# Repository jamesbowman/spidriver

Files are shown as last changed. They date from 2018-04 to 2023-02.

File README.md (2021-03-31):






Full documentation is at
[spidriver.com](https://spidriver.com).

SPIDriver is a tool for controlling any SPI device from your PC's USB port.
It connects as a standard USB serial device, so there are no drivers to install.
The serial protocol is [very simple](/protocol.md),
and there are included drivers for

* Windows/Mac/Linux GUI
* Windows/Mac/Linux command-line
* Python 2 and 3
* Windows/Mac/Linux C/C++

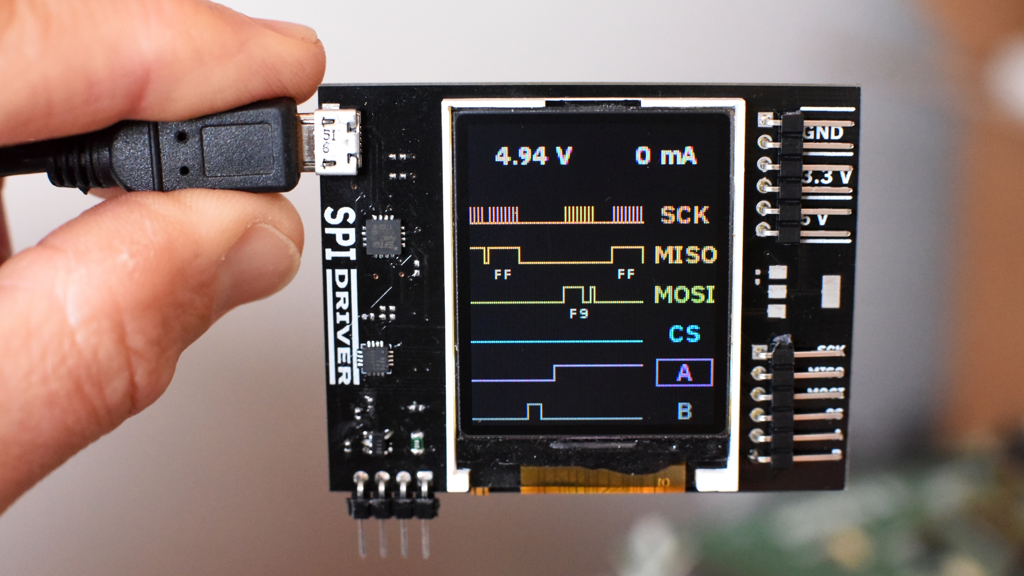
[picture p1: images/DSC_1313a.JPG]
front


## Contributed language bindings

The following bindings were contributed by SPIDriver community members:

* **.net** https://github.com/alandoherty/spidriver-net
* **rust** https://docs.rs/spidriver/0.1.0/spidriver/

[spidriver.com](https://spidriver.com)

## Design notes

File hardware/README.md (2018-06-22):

This is the PCB for the SPIDriver.
It uses a [SKiDL](https://github.com/xesscorp/skidl) to define the netlist.

PCB layout is done in KiCAD's pcbnew:

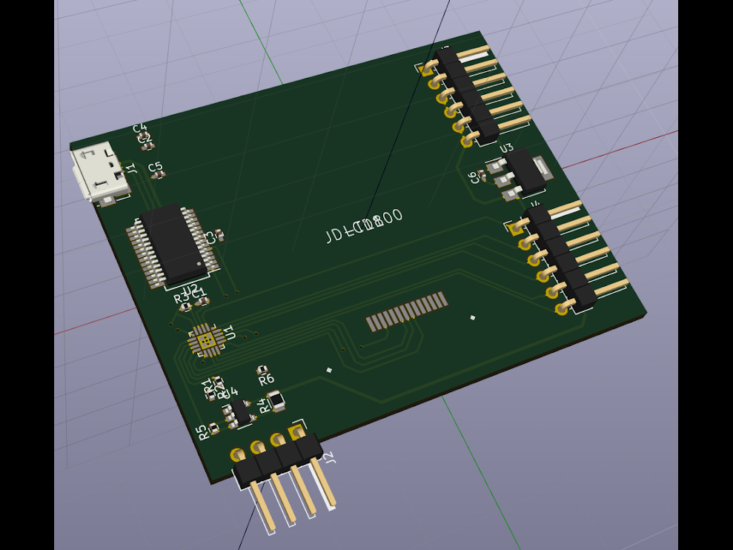
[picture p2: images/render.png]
pcbnew


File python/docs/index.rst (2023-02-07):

spidriver
=========

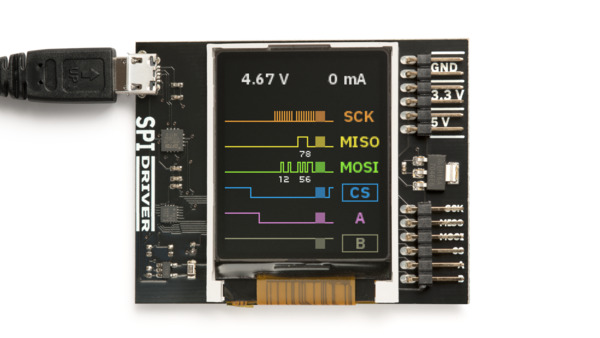
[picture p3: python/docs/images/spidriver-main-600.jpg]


`SPIDriver <https://spidriver.com>`_
is an easy-to-use, open source tool for controlling SPI devices over USB.
It works with Windows, Mac, and Linux, and has a built-in color screen
that shows a live "dashboard" of all the SPI activity.

.. toctree::
   :maxdepth: 2
   :caption: Contents:

The SPIDriver User Guide has complete information on the hardware:

https://spidriver.com/spidriver.pdf

System Requirements
===================

Because it is a pure Python module, ``spidriver`` can run on any system supported by ``pyserial``.
This includes:

- Windows 7 or 10
- Mac OS
- Linux, including all Ubuntu distributions

Both Python 2.7 and 3.x are supported.

Installation
============

The ``spidriver`` package can be installed from PyPI using ``pip``::

    $ pip install spidriver

Quick start
===========

To connect to an SPI flash and read its JEDEC id:

    >>> from spidriver import SPIDriver
    >>> s = SPIDriver("/dev/ttyUSB0") # change for your port
    >>> s.sel() # start command
    >>> s.write([0x9f]) # command 9F is READ JEDEC ID
    >>> list(s.read(3)) # read next 3 bytes
    [239, 64, 24]
    >>> s.unsel() # end command

The User Guide at https://spidriver.com/spidriver.pdf has more examples,
as does the
`SPIDriver repo on github <https://github.com/jamesbowman/spidriver/tree/master/python/samples>`_.

Module Contents
===============

.. autoclass:: spidriver.SPIDriver
   :member-order: bysource
   :members:
      sel,
      unsel,
      detach,
      read,
      write,
      writeread,
      seta,
      setb,
      setmode,
      getstatus

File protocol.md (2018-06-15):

Commands are:

    ?        transmit status info
    e <byte> echo <byte>
    s        select
    u        unselect
    a <byte> set A signal to 0/1
    b <byte> set B signal to 0/1
    x        disconnect from SPI bus
    80-bf    write and read 1-64 bytes
    c0-ff    write 1-64 bytes

So for example to select, then transfer two bytes 0x12, and unselect, the host sends 5 bytes:

    s
    0x81
    0x12
    0x34
    u

The command 0x81 is a two byte send/receive, so two bytes are returned to the PC.

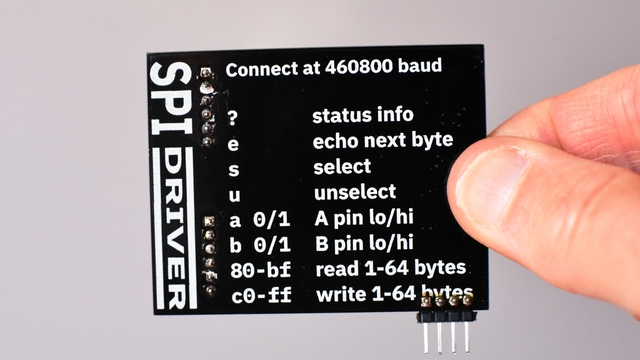
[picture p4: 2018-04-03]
images/small/DSC_1315a.JPG

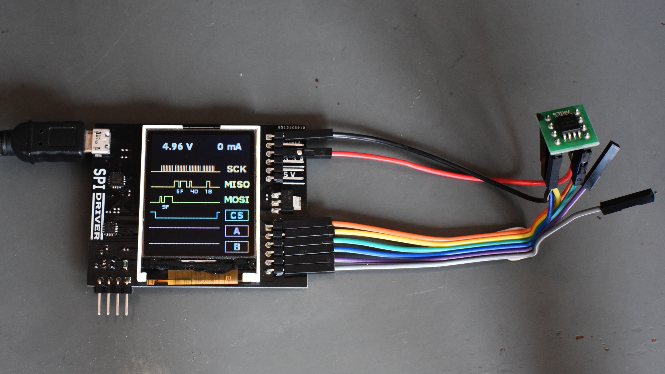
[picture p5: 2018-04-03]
images/DSC_1319a.JPG

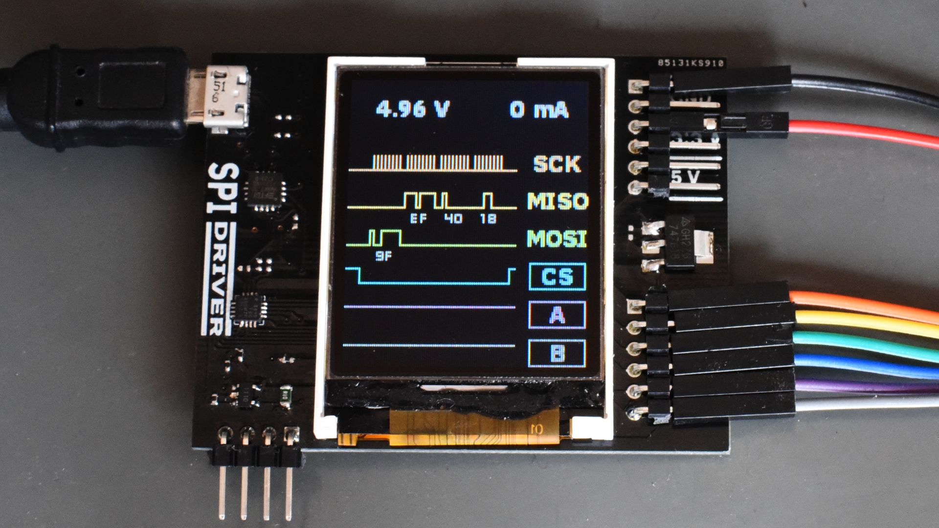
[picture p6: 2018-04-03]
images/DSC_1319b.JPG

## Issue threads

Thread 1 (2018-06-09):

Delightful project ... quick question(s)

RandoSY, 2018-06-09:
Hello!

Just wondering when you were going to follow up you introductory video (FEB SVFIG), and further clarify/share the amazing SiLab EFM8 My-forth tool-chain you built for this project?

Are your plans still on track to crowdfund your SPI monitor? Thanks for all your hard work on this!

Randy

jamesbowman, 2018-06-10:
Hi Randy,

Talking at June Svfig: definitely maybe. I'm not 100% sure I can attend Saturday.

The SPIDriver will launch in a few days. So many fingers are crossed. Please tell anyone who might be interested -- thanks!

RandoSY, 2018-06-15:
James,

150$ funded in TWO DAYS? Wow, you sir, are the man!

I will hope you share you tool set along the way J Gotta be some awesome real time performance in your rig…

Best,

Randy

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

jamesbowman, 2018-08-30:
Never did make it to the SVfig meeting... maybe Forth day 2018 in November!

Closed 2018-08-30.

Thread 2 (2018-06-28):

Passive monitoring?

osterwood, 2018-06-28:
In the future, could the SPI Driver be used to monitor traffic between an external SPI master and slave?

In this mode, I’d love to set a target byte sequence / trigger via the API and a number of bytes to read out once that trigger is seen.  Or the hardware could just provide a continuous stream of data to the computer and triggering / masking could happen there.

jamesbowman, 2019-04-14:
On "must have" list for next version. Closing.

Closed 2019-04-14.

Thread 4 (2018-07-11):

Document MOSI/MISO line sharing

jamesbowman, 2018-07-11:
Using a diode like the circuit used here:
https://github.com/dcwbrown/dwire-debug

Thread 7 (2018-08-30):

win32 spigui should cope properly with multiple serial devices

jamesbowman, 2018-08-30:
When there is one serial device, it should just connect to it.

But when there are multiple serial devices, it should not connect, and wait for the user to pick one from the pulldown.

jamesbowman, 2018-08-30:
Fixed, closing.

Closed 2018-08-30.

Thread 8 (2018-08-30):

Command-line should have a 't' command for bidirectional transfer

jamesbowman, 2018-08-30:
't' should act like 'w', but print out the received bytes.

Suggested in this thread:
http://gameduino2.proboards.com/thread/852/spidriver-running-gameduino3?page=1&scrollTo=2221

maxnil, 2019-06-15:
Any progress on this?

0xStuart, 2021-07-11:
Is that why I cant seem to get anything out of the Atmel M90E26?  You have to write 8 bits, and it immediately returns 16 bits.  Except I see nothing.

This is from the manual.

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

On the spidriver, I see the clock being interrupted, between flipping between write and read.

jamesbowman, 2021-07-11:
This diagram looks half-duplex, so the right sequence should be:

    spicl <device> s w 0x40 r 2 u

0xStuart, 2021-07-11:
It operates like it's half-duplex, but the manual says full-duplex.
The SCK doesn't look the same as the diagram, don't know if that's relevant.

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

jamesbowman, 2021-07-11:
This looks fine - the gaps on SCK are just the inter-byte pauses.

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

Hmm, one idea... datasheet does say that it expects a '1' bit before the 7-bit register address. So changing 0x49 there to 0xc9 might work?

0xStuart, 2021-07-12:
Good call. That wasn't quite it, but I got it working.  I discovered I have a different chip variation to the manual.  Thanks.

benner, 2023-09-13:
I have same issue - I need to receive same time I'm transmitting (full duplex).

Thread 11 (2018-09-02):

Under WSL, no serial device appears

jamesbowman, 2018-09-02:
Reported by @gojimmypi:

> Device is not currently supported in [WSL](https://docs.microsoft.com/en-us/windows/wsl/about), as no device appears in /dev/

jamesbowman, 2018-09-02:
This blog entry explains their naming conventions:

https://blogs.msdn.microsoft.com/wsl/2017/04/14/serial-support-on-the-windows-subsystem-for-linux/

So I would expect ``COM16`` to appear under WSL as ``/dev/ttyS16`` - does this make sense?

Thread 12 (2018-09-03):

Make a proper package for Mac

jamesbowman, 2018-09-03:
Is currently a raw executable. Should be a proper package.

jamesbowman, 2018-09-03:
Walkthough:

http://juusosalonen.com/post/139067064745/demystifying-pkgbuild-in-os-x

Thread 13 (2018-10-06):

All indicators colored bars full all the times.

kirill-chilingarashvili, 2018-10-06:
I just had a chance to test a device,
The voltage above and current indicators work as expected,
bu all of
- SCK
- MISO
- MOSI
- CS
- A
- B

bars are filled with color all the time.
I tried to follow the tutorials - the border around CS, A symbols blink, but the bars designated to show signal are filled all the time.
I tried the image rendering (TFT demo) sample, and the TFT is white and bars are filler.

I am sorry for noob question -  really just got my SPIDriver and tried to follow the tutorials

Can you please help me - where to start debugging this

jamesbowman, 2018-10-06:
Definitely sounds like a hardware issue. Email me at jamesb@excamera.com to arrange a replacement.

Closed 2019-04-14.

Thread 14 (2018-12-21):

Absolutelly unclear instructions

Kabron287, 2018-12-21:
Windows 10 x64
executing **pip install pillow spidriver**
I got a huge output with meaningnone sense. See attach.
[pip_output.txt](https://github.com/jamesbowman/spidriver/files/2702348/pip_output.txt)

executing **python spigui.py**
I got
`d:\Down\SPI_Driver\spidriver-master\python\samples>python spigui.py
Traceback (most recent call last):
  File "spigui.py", line 9, in <module>
    import wx
ImportError: No module named 'wx'`
and so on, nothing works.
 maybe instructions have to be more comprehensive?

MartyMacGyver, 2019-01-30:
Short story: Install Python 3.6 or 3.7 (I'm using 3.7) and use that. I suspect your old Python 3.4 is the first problem here.

Longer story: Even then the gui won't work, because it's only made to enumerate ports on OSX and Linux. However, once you know what port you're on (e.g., "`COM3:`"), you can make a simple hack of spigui.py to make it work:

After the line `self.devs = self.devices()`
Add the line `self.devs = {'COM3:': 'COM3:'}` (with your COM port in it)

Then it (hopefully) will work better. Mine works with this.

I'd also suggest you update the title here to be more informative - something like "Unable to run samples using Windows 10" since that's really the main problem here.

jamesbowman, 2019-01-30:
@Kabron287 was getting an error because of missing 'wx' - is it included in Python 3.7 on Windows?

Or did you install wx by doing something like:
https://wxpython.org/pages/downloads/index.html

I have opened #17 for the port enumeration problem. Thanks

MartyMacGyver, 2019-01-30:
The warnings about python_requires and the `The headers or library files could not be found for zlib, a required dependency when compiling Pillow from source.` error are what I see in their logfile here. The former suggests outdated Python, but the latter is because Pillow is being compiled (a binary wheel would be the way to go for that.) Maybe updating pip would allow that, but installing a current Python might be a better way to go to get a functional install - 3.4 is also just about EOL:

https://www.python.org/dev/peps/pep-0429/

jamesbowman, 2019-04-14:
Python GUI should:
- [ ] catch missing wx and show a helpful message
- [ ] enumerate ports properly on Windows

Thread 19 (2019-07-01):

Python code does not properly calculate size / does not properly handle some devices

dshadoff, 2019-07-01:
While trying to identify/read a 8KB FeRAM device MB85RS64V, the JEDEC ID is properly identified (0x04 0x7F 0x03), but the python code then goes into an infinite loop grabbing JEDEC ID again and again instead of determining memory size (which is 64 kbit / 8KB).

Product was purchased here: https://www.adafruit.com/product/1897
Datasheet here: http://www.adafruit.com/datasheets/MB85RS64V-DS501-00015-4v0-E.pdf

Likewise, a 128KB FeRAM MR45V100A was properly identified as (0xae 0x83 0x09), but was improperly identified as 512 bytes (actual size = 1Mbit / 128KB).

jamesbowman, 2019-07-01:
Fixed the infinite loop bug, and pushed to PyPI:
https://pypi.org/project/spidriver/

You can specify the size on the command-line using the ``-s`` argument, so for the MB85RS64V use ``-s 65536``, and for MR45V100A ``-s 131072``. This is meant for parts where the size isn't computable from the third ID byte, like these.

However reading further down the MB85RS64V datasheet, I see that it uses 16-bit addresses, and the flash tool assumes 24-bit addresses.
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

However the MR45V100A does use 24-bit addressing, so it might work - please let me know.
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

dshadoff, 2019-07-02:
Thanks, the infinite loop bug appears to be fixed.

The third-byte size computation... may not be as straightforward as you had thought.
I tested a AT25SF041 (very common 4Mb / 512KB Flash), which has JEDEC ID (0x1f 0x84 0x01)... this clearly also doesn't follow your expected rules.

As a result, it would be helpful if the spidriver.pdf file could be updated with this point about memory size, including the '-s <size>' operand for the python script.

bitshiftnetau, 2020-08-10:
Not fixed. Trying to read a [winbond 25Q64/32f](https://www.winbond.com/resource-files/w25q64fv%20revq%2006142016.pdf) and the output "Got JEDEC ID: xx xx xx" outputs on infinite loop. It does get the JEDEC ID.

I have tried connecting the WP and HOLD pins (3 & 5 respectively) to A and B and all 3 combinations of each i.e. WP & HOLD, just WP, just HOLD and nothing seems to work.

I am running:

`python flash.py -h /dev/ttyUSB0`

And have confirmed it does not work when the device and indeed the clip itself are not connected.

I have an updated version of spidriver installed and I am using the following flash.py example code:

```

#!/usr/bin/env python3

from spidriver import SPIDriver
import struct
import time
import sys
import getopt

def hexdump(s):
    def toprint(c):
        if 32 <= c < 127:
            return chr(c)
        else:
            return "."
    def hexline(s):
        bb = struct.unpack("16B", s)
        return (" ".join(["%02x" % c for c in bb]).ljust(49) +
                "|" + "".join([toprint(c) for c in bb]).ljust(16) + "|")
    return "\n".join([hexline(s[i:i+16]) for i in range(0, len(s), 16)])

if __name__ == '__main__':
    try:
        optlist, args = getopt.getopt(sys.argv[1:], "h:r:w:s:")
    except getopt.GetoptError as reason:
        print()
        print('usage: flash [ -h device ] [ -r file ] [ -w file ] [-s size]')
        print()
        print()
        sys.exit(1)
    optdict = dict(optlist)

    s = SPIDriver(optdict.get('-h', "/dev/ttyUSB0"))
    s.seta(0)
    s.unsel()

    size = int(optdict.get('-s', "0"))

                                # Some primitives for generic flash
    def command(b):
        s.unsel()
        s.sel()
        s.writeread(b)

    def idcode():
        command([0x9f])
        return s.read(3)

    def write_enable():
        command([0x06])

    def status():
        command([0x05])
        (r,) = struct.unpack("B", s.read(1))
        return r

    def wait_ready():
        while True:
            r = status()
            if (r & 1) == 0:
                break

    def addr24(a):
        return [(a >> 16) & 0xff, (a >> 8) & 0xff, a & 0xff]

    def page_program(a, b256):
        # print('page_program', a)
        write_enable()
        command([0x02] + addr24(a))
        s.writeread(b256)
        wait_ready()

    def erase_sector(a):
        # print('erase sector', a)
        write_enable()
        command([0xd8] + addr24(a))
        wait_ready()

    def read(a):
        command([0x03] + addr24(a))

    while True:
        ids = struct.unpack("BBB", idcode())
        print("Got JEDEC ID: %02x %02x %02x" % ids)
        if size > 0:
            break
        if ids[0] not in (0x00, 0xff) and (1 <= ids[2] < 22):
            break
    if size == 0:
        size = 1 << ids[2]
    print("Flash size is %d bytes" % size)

    print("Status is %02x" % status())

    if '-r' in optdict:
        read(0)
        chunk = 8 * 1024
        size,chunk = 128,128
        with open(optdict['-r'], "wb") as f:
            for a in range(0, size, chunk):
                d = s.read(chunk)
                print(d)
                f.write(d)
                print("%d/%d KBytes" % (a / 1024, size / 1024))
    if '-w' in optdict:
        write_enable()
        command([0xc7])
        wait_ready()
        with open(optdict['-w'], "rb") as f:
            for a in range(0, size, 256):
                d = f.read(256)
                if len(d) == 0:
                    break
                page_program(a, d)
                print("%d/%d KBytes" % (a / 1024, size / 1024))
    write_enable()

    s.unsel()
    s.seta(1)
    s.detach()

```

biboc, 2022-11-04:
Agree with @dshadoff , size calculation does not work as expected for my m25p20 memory
https://media-www.micron.com/-/media/client/global/documents/products/data-sheet/nor-flash/serial-nor/m25p/m25p20.pdf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

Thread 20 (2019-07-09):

spidriver.pdf instructions for SPI Flash should connect /HOLD

dshadoff, 2019-07-09:
While using SPIFlash to read/write FeRAM device MR45V100A, I found that JEDEC ID was identified as {0x00, 0x00, 0x00} 90-99% of the time when the /HOLD line (pin 7 on SOP package) was left unconnected (as is demonstrated in the spidriver.pdf instruction file).

The datasheet for the device implied that both loose wires (/WP and /HOLD) should be brought to a logic "high", but I found that the JEDEC ID required just bringing /HOLD high.

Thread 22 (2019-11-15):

How can I debug, readout MOSI, MISO, CLK & CS from working Device under Test (DUT)

Hbra9774, 2019-11-15:
Is it possible with SPIdriver to monitor, Log a SPI-bus in a DUT ?

jamesbowman, 2019-11-15:
SPIDriver is output-only, it cannot monitor or log from an existing SPI bus.

Closed 2019-11-15.

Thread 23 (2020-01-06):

Would love build instructions for the GUIs

bitshiftnetau, 2020-01-06:
Doesn't seem to be a Makefile or any build instructions for the GUIs, I know you host the executables and that's great but seeing as you've opened the source it would be great to build from there.

Thoughts?

jamesbowman, 2020-01-06:
The Windows GUI is cross-compiled on Linux, the Makefile is in C/win32gui:

https://github.com/jamesbowman/spidriver/tree/master/c/win32gui

The Linux.Mac GUI is the Python gui.py
https://github.com/jamesbowman/spidriver/blob/master/python/samples/gui.py

It is made into an executable with `pyinstaller` - the I2CDriver Readme gives the command-line:

https://github.com/jamesbowman/i2cdriver

bitshiftnetau, 2020-01-06:
Awesome man, I've built a package for Arch Linux that builds spicl and also a shared library, then installs to the system. I'll do the same for the GUIs based on your instructions above.

Also, just a side note: this device is the best thing I have ever purchased. Thank you!

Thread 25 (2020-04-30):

Mode control - how?

mgaman, 2020-04-30:
How can I set modes 0-3? From what I see on the screen SCLK polarity is always Idle at 0.
There are no instructions as how to change it

jamesbowman, 2020-04-30:
Yes, that is correct. SPIDriver only runs in mode 0.

What device do you have that runs in another mode?

mgaman, 2020-05-01:
I don't, yet but do anticipate in the near future.
Can it be changed via the serial connection or is it hard wired in the device firmware?

nicktramp, 2020-07-22:
I was looking to use SPIDriver with the [Melexis MLX90393](https://www.melexis.com/en/product/MLX90393/Triaxis-Micropower-Magnetometer), which uses SPI mode 3. Are other modes planned? I would offer to help implement, but I've never encountered Forth outside this project, so I'm afraid I wouldn't be much help...

movingfox, 2022-02-13:
I can see that it's hard to be done because the firmware needs to drive st7735s at SPI mode 0 as well. Could you release a 'blind' version of firmware for those who'd like to have spidriver2 mode selection ? That seems to be a dirty but quick fix.

By the way, the file `cal-b3.fs` is missing in the firmware folder. Could you upload it?

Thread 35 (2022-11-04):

flash.py: size is erased with read option

biboc, 2022-11-04:
I read my SPI memory with

The flash.py program reads only two bytes, why?
In the code, I don't get why you replace size variable at line https://github.com/jamesbowman/spidriver/blob/master/python/samples/flash.py#L97

```
    if '-r' in optdict:
        read(0)
        chunk = 8 * 1024
        size,chunk = 128,128
        with open(optdict['-r'], "wb") as f:
```

By commenting the line `size,chunk = 128,128`, it works

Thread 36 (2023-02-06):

Pause between SPI transactions

Rodgers-PAC-Lab, 2023-02-06:
I'm trying to read data from a sensor with a pretty fast sample rate, so I'm looking to get pretty close to the 500 kbps rate on the SPIDriver. I'm using one of the cheap Salae-8 knockoff logic analyzers and Pulseview for troubleshooting. I noticed that, while the actual SPI transactions are measuring 490 kHz, there's always a 30 microsecond pause between bytes.

What's the reason for these pauses, and is there any way to remove the delays? Here's a screenshot of what I see in Pulseview (sampling at 24 MHz) when I use the read(10) command to read 10 bytes.

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

jamesbowman, 2023-02-06:
That is puzzling. I expect there to be very little time between bytes.
For ``read(10)`` there's  be a delay every **10** bytes, because of the API overhead, but not every byte.

Couple of questions:

Is that ``read(10)`` in Python?

Please can you post a zoomed-out screenshot to confirm the inter-byte delay?

Rodgers-PAC-Lab, 2023-02-06:
Yeah, it's in Python. Just s = SPIDriver("/dev/SPIDriver"), then some setup code where I use a and b outputs to toggle a reset pin and start pin to wake up the peripheral, then s.read(10) and that's what I get.

The device is an ADS1299 EEG chip, but I'm pretty sure it's not an issue with the device. When I snoop on its SPI transactions with TI's demo software it doesn't have any gaps in SCLK. I could try SPIDriver with a different peripheral if you think that's worth checking though.

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

jamesbowman, 2023-02-06:
I'm just running the SPIDriver on the bench here and I see the same thing. The issue is that SPIDriver uses two-way communication to implement reads. (SPI **Writes** are fast, which is my confusion.) This introduces a read-write latency over the USB.

So yes, unfortunately this is a feature of the SPIDriver, at least the current version.

Have you set the USB latency timer to zero? That might help in this case:

    setserial /dev/<tty_name> low_latency

Rodgers-PAC-Lab, 2023-02-06:
Alas, that didn't change much. Brought it down to 29 us.

That makes sense though, thanks for explaining it. Even if SPIDriver isn't fast enough for our final application it's been a great troubleshooting tool.

Rodgers-PAC-Lab, 2023-02-09:
Quick question: would this also happen if we used the C/C++ driver? I see that the EFM8BB1 MCU datasheet claims speeds up to 24 MHz. I'm way less competent in C though, so I'd hate to spend the time figuring it out only to learn it's still too slow.

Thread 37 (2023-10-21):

Use with modm platform

botoxparty, 2023-10-21:
Hi,

I would love to be able to use this device with [modm](https://github.com/modm-io/modm).

I unfortunately don't have the in-depth knowledge of developing linux drivers to be able to refactor the existing linux driver to be compatible with the project. See https://github.com/modm-io/modm/issues/1094

If anyone would support me with developing this I would love to work together.

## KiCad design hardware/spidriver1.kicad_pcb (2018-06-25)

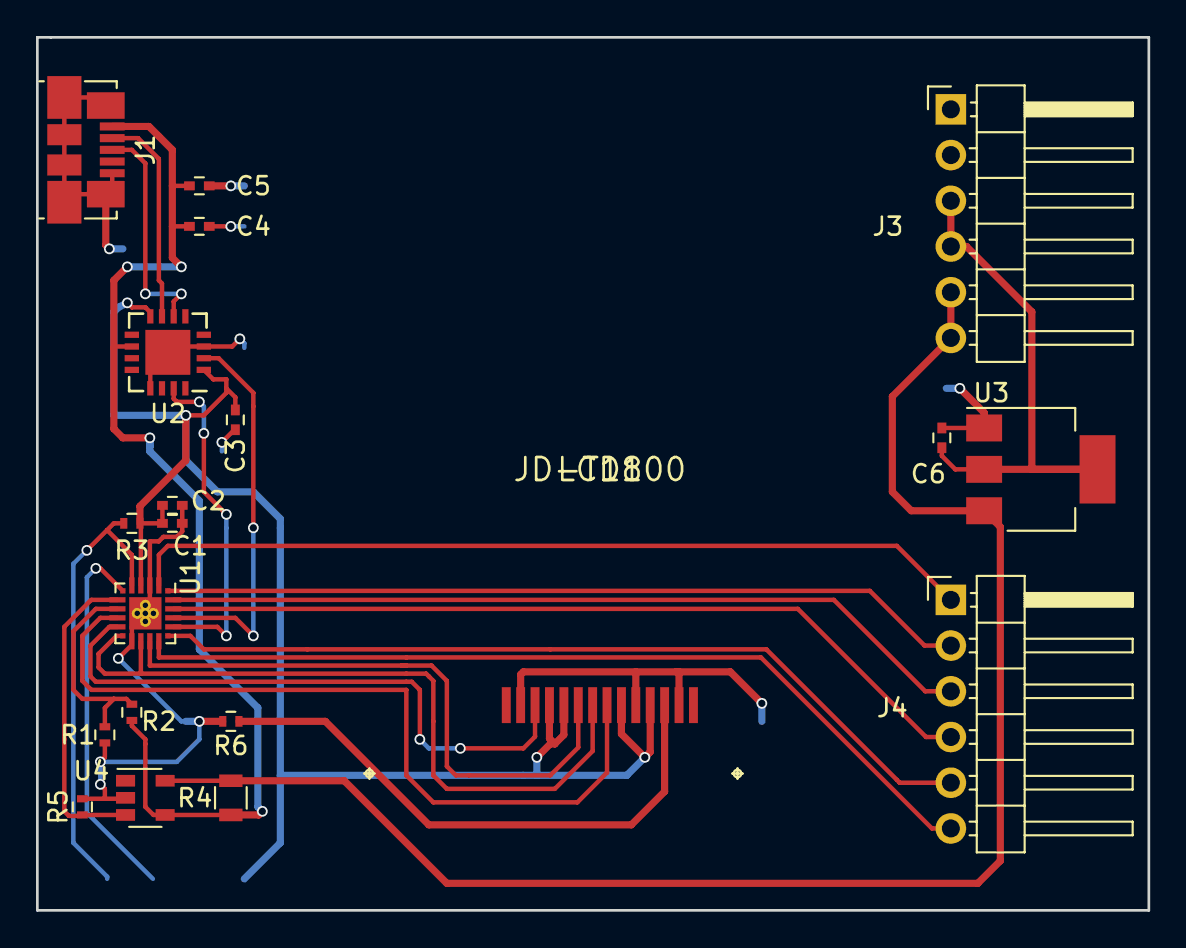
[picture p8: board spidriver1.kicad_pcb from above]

Board: 2 copper layers, 61.8 x 48.5 mm, 21 parts (1 on the bottom side), 24 nets.

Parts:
C1, C3, C4, C6: 0.1uF; C_0402
C2: 1uF; C_0402
C5: 10uF; C_0402
J1: USB_OTG; USB_Micro-B_Molex_47346-0001
J2: Conn_01x04_Male; POGO4
J3, J4: Conn_01x06_Male; Pin_Header_Angled_1x06_Pitch2.54mm
LCD1: JD-T1800
R1: 1180; R_0402
R2: 1000; R_0402
R3: 1K; R_0402
R4: .1; R_0805
R5: 12K; R_0402
R6: 22; R_0402
U1: EFM8BB10F8G-A-QFN20; SiliconLabs_QFN-20-1EP_3x3mm_Pitch0.5mm_ThermalVias
U2: FT230XQ; QFN-16-1EP_4x4mm_Pitch0.65mm
U3: AP1117-15; SOT-223-3Lead_TabPin2
U4: ZXCT1110; SOT-23-5

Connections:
3.3V: C1.1, C2.1, C3.1, J2.1, LCD1.4, LCD1.6, LCD1.10, LCD1.11, R3.2, U1.4, U2.1, U2.8
3.3VB: C6.1, J3.3, J3.4, U3.2
5V: C4.1, C5.1, J1.1, R1.1, R4.1, U2.10, U4.4
5VB: J3.5, J3.6, R4.2, U3.3, U4.5
GND: C1.2, C2.2, C3.2, C4.2, C5.2, C6.2, J1.5, J1.6, J2.2, J3.1, J3.2, LCD1.2, LCD1.5, LCD1.13, R2.2, R5.2, R6.2, U1.3, U1.12, U1.21, U2.3, U2.13, U2.17, U3.1, U4.2
unnamed: R1.2, R2.1, U1.8
unnamed: J2.4, R3.1, U1.5
unnamed: U1.18, U2.2
unnamed: U1.17, U2.15
unnamed: R5.1, U1.7, U4.3
unnamed: J2.3, U1.6
unnamed: J4.1, U1.2
unnamed: J4.2, U1.1
unnamed: J4.3, U1.20
unnamed: J4.4, U1.19
unnamed: J4.5, U1.16
unnamed: J4.6, U1.15
unnamed: LCD1.9, U1.14
unnamed: LCD1.8, U1.11, U1.13
unnamed: LCD1.12, U1.10
unnamed: LCD1.7, U1.9
unnamed: LCD1.3, R6.1
unnamed: J1.3, U2.6
unnamed: J1.2, U2.7

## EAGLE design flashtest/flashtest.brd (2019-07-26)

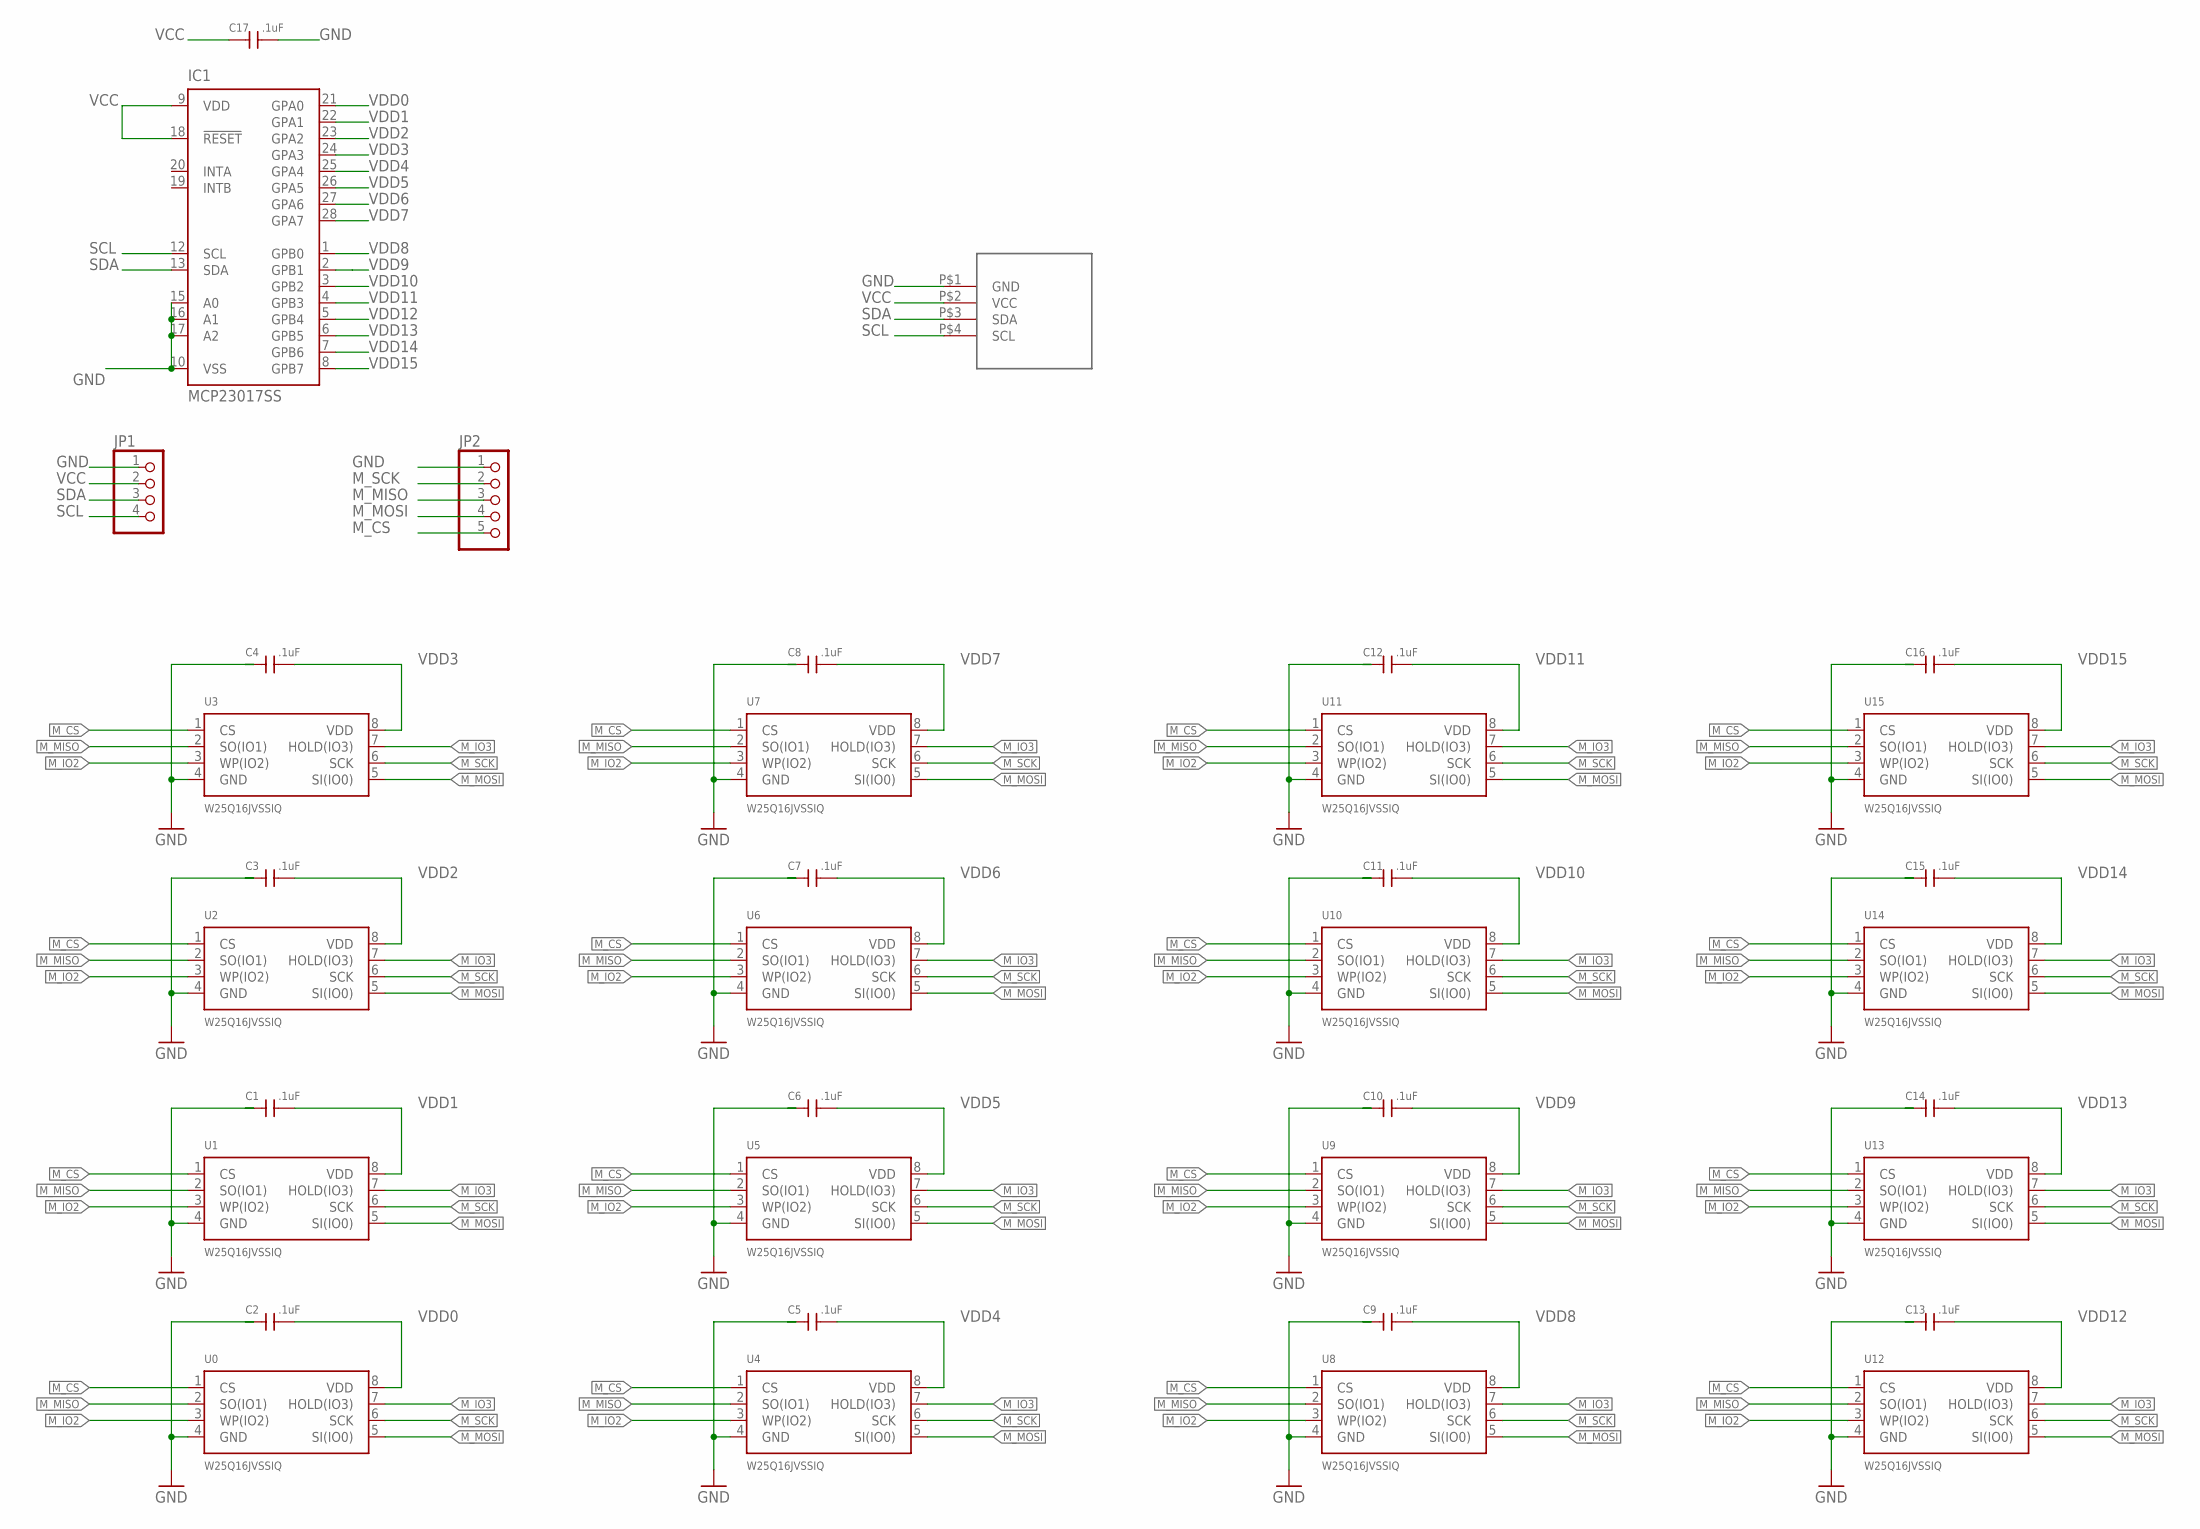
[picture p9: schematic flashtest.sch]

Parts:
C1, C2, C3, C4, C5, C6, C7, C8, C9, C10, C11, C12, C13, C14, C15, C16, C17: .1uF; 0603@1
IC1: MCP23017SS; SSOP28
JP1: PINHD-1X4; 1X04
JP2: PINHD-1X5; 1X05
U0, U1, U2, U3, U4, U5, U6, U7, U8, U9, U10, U11, U12, U13, U14, U15: W25Q16JVSSIQ; SOIC-8
U$1: I2C

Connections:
GND: C1.1, C2.1, C3.1, C4.1, C5.1, C6.1, C7.1, C8.1, C9.1, C10.1, C11.1, C12.1, C13.1, C14.1, C15.1, C16.1, C17.2, IC1.10 (VSS), IC1.15 (A0), IC1.16 (A1), IC1.17 (A2), JP1.1, JP2.1, U0.4 (GND), U1.4 (GND), U2.4 (GND), U3.4 (GND), U4.4 (GND), U5.4 (GND), U6.4 (GND), U7.4 (GND), U8.4 (GND), U9.4 (GND), U10.4 (GND), U11.4 (GND), U12.4 (GND), U13.4 (GND), U14.4 (GND), U15.4 (GND), U$1.P$1 (GND)
M_CS: JP2.5, U0.1 (CS), U1.1 (CS), U2.1 (CS), U3.1 (CS), U4.1 (CS), U5.1 (CS), U6.1 (CS), U7.1 (CS), U8.1 (CS), U9.1 (CS), U10.1 (CS), U11.1 (CS), U12.1 (CS), U13.1 (CS), U14.1 (CS), U15.1 (CS)
M_IO2: U0.3 (WP(IO2)), U1.3 (WP(IO2)), U2.3 (WP(IO2)), U3.3 (WP(IO2)), U4.3 (WP(IO2)), U5.3 (WP(IO2)), U6.3 (WP(IO2)), U7.3 (WP(IO2)), U8.3 (WP(IO2)), U9.3 (WP(IO2)), U10.3 (WP(IO2)), U11.3 (WP(IO2)), U12.3 (WP(IO2)), U13.3 (WP(IO2)), U14.3 (WP(IO2)), U15.3 (WP(IO2))
M_IO3: U0.7 (HOLD(IO3)), U1.7 (HOLD(IO3)), U2.7 (HOLD(IO3)), U3.7 (HOLD(IO3)), U4.7 (HOLD(IO3)), U5.7 (HOLD(IO3)), U6.7 (HOLD(IO3)), U7.7 (HOLD(IO3)), U8.7 (HOLD(IO3)), U9.7 (HOLD(IO3)), U10.7 (HOLD(IO3)), U11.7 (HOLD(IO3)), U12.7 (HOLD(IO3)), U13.7 (HOLD(IO3)), U14.7 (HOLD(IO3)), U15.7 (HOLD(IO3))
M_MISO: JP2.3, U0.2 (SO(IO1)), U1.2 (SO(IO1)), U2.2 (SO(IO1)), U3.2 (SO(IO1)), U4.2 (SO(IO1)), U5.2 (SO(IO1)), U6.2 (SO(IO1)), U7.2 (SO(IO1)), U8.2 (SO(IO1)), U9.2 (SO(IO1)), U10.2 (SO(IO1)), U11.2 (SO(IO1)), U12.2 (SO(IO1)), U13.2 (SO(IO1)), U14.2 (SO(IO1)), U15.2 (SO(IO1))
M_MOSI: JP2.4, U0.5 (SI(IO0)), U1.5 (SI(IO0)), U2.5 (SI(IO0)), U3.5 (SI(IO0)), U4.5 (SI(IO0)), U5.5 (SI(IO0)), U6.5 (SI(IO0)), U7.5 (SI(IO0)), U8.5 (SI(IO0)), U9.5 (SI(IO0)), U10.5 (SI(IO0)), U11.5 (SI(IO0)), U12.5 (SI(IO0)), U13.5 (SI(IO0)), U14.5 (SI(IO0)), U15.5 (SI(IO0))
M_SCK: JP2.2, U0.6 (SCK), U1.6 (SCK), U2.6 (SCK), U3.6 (SCK), U4.6 (SCK), U5.6 (SCK), U6.6 (SCK), U7.6 (SCK), U8.6 (SCK), U9.6 (SCK), U10.6 (SCK), U11.6 (SCK), U12.6 (SCK), U13.6 (SCK), U14.6 (SCK), U15.6 (SCK)
SCL: IC1.12 (SCL), JP1.4, U$1.P$4 (SCL)
SDA: IC1.13 (SDA), JP1.3, U$1.P$3 (SDA)
VCC: C17.1, IC1.9 (VDD), IC1.18 (!RESET), JP1.2, U$1.P$2 (VCC)
VDD0: C2.2, IC1.21 (GPA0), U0.8 (VDD)
VDD1: C1.2, IC1.22 (GPA1), U1.8 (VDD)
VDD2: C3.2, IC1.23 (GPA2), U2.8 (VDD)
VDD3: C4.2, IC1.24 (GPA3), U3.8 (VDD)
VDD4: C5.2, IC1.25 (GPA4), U4.8 (VDD)
VDD5: C6.2, IC1.26 (GPA5), U5.8 (VDD)
VDD6: C7.2, IC1.27 (GPA6), U6.8 (VDD)
VDD7: C8.2, IC1.28 (GPA7), U7.8 (VDD)
VDD8: C9.2, IC1.1 (GPB0), U8.8 (VDD)
VDD9: C10.2, IC1.2 (GPB1), U9.8 (VDD)
VDD10: C11.2, IC1.3 (GPB2), U10.8 (VDD)
VDD11: C12.2, IC1.4 (GPB3), U11.8 (VDD)
VDD12: C13.2, IC1.5 (GPB4), U12.8 (VDD)
VDD13: C14.2, IC1.6 (GPB5), U13.8 (VDD)
VDD14: C15.2, IC1.7 (GPB6), U14.8 (VDD)
VDD15: C16.2, IC1.8 (GPB7), U15.8 (VDD)

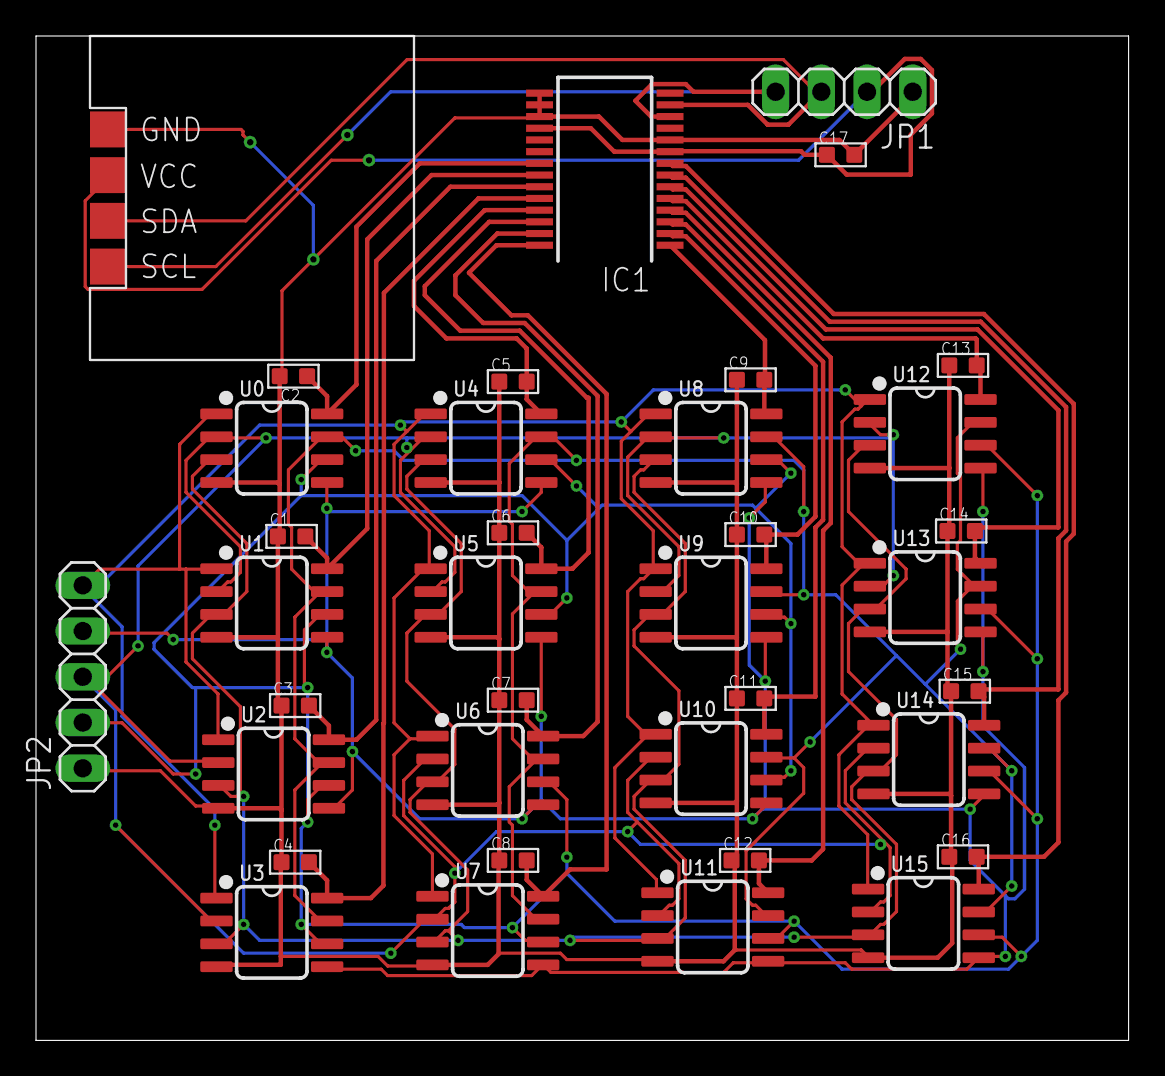
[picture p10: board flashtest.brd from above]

Board: 2 copper layers, 60.7 x 55.8 mm, 37 parts (0 on the bottom side), 26 nets.

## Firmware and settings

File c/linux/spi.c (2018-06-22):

#include <stdio.h>
#include <stdlib.h>

#include "spidriver.h"

int main(int argc, char *argv[])
{
  SPIDriver sd;
  if (argc < 2) {
    printf("Usage: spicl <PORTNAME> <commands>\n");
    exit(1);
  } else {
    spi_connect(&sd, argv[1]);
    if (!sd.connected)
      exit(1);
    return spi_commands(&sd, argc - 2, argv + 2);
  }
}

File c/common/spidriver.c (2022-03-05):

#include <stdio.h>
#include <stdlib.h>
#include <assert.h>
#include <memory.h>
#include <fcntl.h>
#if !defined(WIN32)
#include <sys/ioctl.h>
#endif
#include <unistd.h>
#include <errno.h>
#define __STDC_FORMAT_MACROS
#include <inttypes.h>
#include <string.h>

#include "spidriver.h"

// ****************************   Serial port  ********************************

#if defined(WIN32)  // {

#include <windows.h>

void ErrorExit(const char *func_name) 
{ 
    // Retrieve the system error message for the last-error code

    LPVOID lpMsgBuf;
    DWORD dw = GetLastError(); 

    FormatMessage(
        FORMAT_MESSAGE_ALLOCATE_BUFFER | 
        FORMAT_MESSAGE_FROM_SYSTEM |
        FORMAT_MESSAGE_IGNORE_INSERTS,
        NULL,
        dw,
        MAKELANGID(LANG_NEUTRAL, SUBLANG_DEFAULT),
        (LPTSTR) &lpMsgBuf,
        0, NULL );

    // Display the error message and exit the process

    char mm[lstrlen((LPCTSTR)lpMsgBuf) + strlen(func_name) + 40];
    sprintf(mm, "%s failed with error %lu:\n%s", func_name, dw, (char*)lpMsgBuf); 
    MessageBox(NULL, (LPCTSTR)mm, TEXT("Error"), MB_OK); 

    LocalFree(lpMsgBuf);
    ExitProcess(dw); 
}

HANDLE openSerialPort(const char *portname)
{
    char fullname[10];
    const char *fmt;
    if (portname[0] == 'C')
        fmt = "\\\\.\\%s";
    else
        fmt == "%s";
    snprintf(fullname, sizeof(fullname), fmt, portname);
    DWORD  accessdirection = GENERIC_READ | GENERIC_WRITE;
    HANDLE hSerial = CreateFile((LPCSTR)fullname,
        accessdirection,
        0,
        0,
        OPEN_EXISTING,
        0,
        0);
    if (hSerial == INVALID_HANDLE_VALUE) {
        ErrorExit("CreateFile");
    }
    DCB dcbSerialParams = {0};
    dcbSerialParams.DCBlength=sizeof(dcbSerialParams);
    if (!GetCommState(hSerial, &dcbSerialParams)) {
         ErrorExit("GetCommState");
    }
    dcbSerialParams.BaudRate = 460800;
    dcbSerialParams.ByteSize = 8;
    dcbSerialParams.StopBits = ONESTOPBIT;
    dcbSerialParams.Parity = NOPARITY;
    if (!SetCommState(hSerial, &dcbSerialParams)) {
         ErrorExit("SetCommState");
    }
    COMMTIMEOUTS timeouts = {0};
    timeouts.ReadIntervalTimeout = 50;
    timeouts.ReadTotalTimeoutConstant = 50;
    timeouts.ReadTotalTimeoutMultiplier = 10;
    timeouts.WriteTotalTimeoutConstant = 50;
    timeouts.WriteTotalTimeoutMultiplier = 10;
    if (!SetCommTimeouts(hSerial, &timeouts)) {
        ErrorExit("SetCommTimeouts");
    }
    return hSerial;
}

DWORD readFromSerialPort(HANDLE hSerial, char * buffer, int buffersize)
{
    DWORD dwBytesRead = 0;
    if (!ReadFile(hSerial, buffer, buffersize, &dwBytesRead, NULL)) {
        ErrorExit("ReadFile");
    }
    return dwBytesRead;
}

DWORD writeToSerialPort(HANDLE hSerial, const char * data, int length)
{
    DWORD dwBytesRead = 0;
    if (!WriteFile(hSerial, data, length, &dwBytesRead, NULL)) {
        ErrorExit("WriteFile");
    }
    return dwBytesRead;
}

void closeSerialPort(HANDLE hSerial)
{
    CloseHandle(hSerial);
}

#else               // }{

#include <termios.h>

int openSerialPort(const char *portname)
{
  struct termios Settings;
  int fd;
  
  fd = open(portname, O_RDWR | O_NOCTTY);
  if (fd == -1) {
    perror(portname);
    return -1;
  }

  tcgetattr(fd, &Settings);
#if defined(__APPLE__) && !defined(B460800)
#define B460800 460800
#endif

  cfsetispeed(&Settings, B460800);
  cfsetospeed(&Settings, B460800);

  cfmakeraw(&Settings);
  Settings.c_cc[VMIN] = 1;
  if (tcsetattr(fd, TCSANOW, &Settings) != 0) {
    perror("Serial settings");
    return -1;
  }

  return fd;
}

size_t readFromSerialPort(int fd, char *b, size_t s)
{
  size_t n, t;
  t = 0;
  while (t < s) {
    n = read(fd, b + t, s);
    if (n > 0)
      t += n;
  }
#ifdef VERBOSE
  printf(" READ %d %d: ", (int)s, (int)n);
  int i;
  for (i = 0; i < s; i++)
    printf("%02x ", 0xff & b[i]);
  printf("\n");
#endif
  return s;
}

void writeToSerialPort(int fd, const char *b, size_t s)
{
  size_t  _ __attribute__((unused)) = write(fd, b, s);
#ifdef VERBOSE
  printf("WRITE %u: ", (int)s);
  int i;
  for (i = 0; i < s; i++)
    printf("%02x ", 0xff & b[i]);
  printf("\n");
#endif
}
#endif              // }

// ******************************  CCITT CRC  *********************************

static const uint16_t crc_table[256] = {
    0x0000, 0x1021, 0x2042, 0x3063, 0x4084, 0x50a5, 0x60c6, 0x70e7,
    0x8108, 0x9129, 0xa14a, 0xb16b, 0xc18c, 0xd1ad, 0xe1ce, 0xf1ef,
    0x1231, 0x0210, 0x3273, 0x2252, 0x52b5, 0x4294, 0x72f7, 0x62d6,
    0x9339, 0x8318, 0xb37b, 0xa35a, 0xd3bd, 0xc39c, 0xf3ff, 0xe3de,
    0x2462, 0x3443, 0x0420, 0x1401, 0x64e6, 0x74c7, 0x44a4, 0x5485,
    0xa56a, 0xb54b, 0x8528, 0x9509, 0xe5ee, 0xf5cf, 0xc5ac, 0xd58d,
    0x3653, 0x2672, 0x1611, 0x0630, 0x76d7, 0x66f6, 0x5695, 0x46b4,
    0xb75b, 0xa77a, 0x9719, 0x8738, 0xf7df, 0xe7fe, 0xd79d, 0xc7bc,
    0x48c4, 0x58e5, 0x6886, 0x78a7, 0x0840, 0x1861, 0x2802, 0x3823,
    0xc9cc, 0xd9ed, 0xe98e, 0xf9af, 0x8948, 0x9969, 0xa90a, 0xb92b,
    0x5af5, 0x4ad4, 0x7ab7, 0x6a96, 0x1a71, 0x0a50, 0x3a33, 0x2a12,
    0xdbfd, 0xcbdc, 0xfbbf, 0xeb9e, 0x9b79, 0x8b58, 0xbb3b, 0xab1a,
    0x6ca6, 0x7c87, 0x4ce4, 0x5cc5, 0x2c22, 0x3c03, 0x0c60, 0x1c41,
    0xedae, 0xfd8f, 0xcdec, 0xddcd, 0xad2a, 0xbd0b, 0x8d68, 0x9d49,
    0x7e97, 0x6eb6, 0x5ed5, 0x4ef4, 0x3e13, 0x2e32, 0x1e51, 0x0e70,
    0xff9f, 0xefbe, 0xdfdd, 0xcffc, 0xbf1b, 0xaf3a, 0x9f59, 0x8f78,
    0x9188, 0x81a9, 0xb1ca, 0xa1eb, 0xd10c, 0xc12d, 0xf14e, 0xe16f,
    0x1080, 0x00a1, 0x30c2, 0x20e3, 0x5004, 0x4025, 0x7046, 0x6067,
    0x83b9, 0x9398, 0xa3fb, 0xb3da, 0xc33d, 0xd31c, 0xe37f, 0xf35e,
    0x02b1, 0x1290, 0x22f3, 0x32d2, 0x4235, 0x5214, 0x6277, 0x7256,
    0xb5ea, 0xa5cb, 0x95a8, 0x8589, 0xf56e, 0xe54f, 0xd52c, 0xc50d,
    0x34e2, 0x24c3, 0x14a0, 0x0481, 0x7466, 0x6447, 0x5424, 0x4405,
    0xa7db, 0xb7fa, 0x8799, 0x97b8, 0xe75f, 0xf77e, 0xc71d, 0xd73c,
    0x26d3, 0x36f2, 0x0691, 0x16b0, 0x6657, 0x7676, 0x4615, 0x5634,
    0xd94c, 0xc96d, 0xf90e, 0xe92f, 0x99c8, 0x89e9, 0xb98a, 0xa9ab,
    0x5844, 0x4865, 0x7806, 0x6827, 0x18c0, 0x08e1, 0x3882, 0x28a3,
    0xcb7d, 0xdb5c, 0xeb3f, 0xfb1e, 0x8bf9, 0x9bd8, 0xabbb, 0xbb9a,
    0x4a75, 0x5a54, 0x6a37, 0x7a16, 0x0af1, 0x1ad0, 0x2ab3, 0x3a92,
    0xfd2e, 0xed0f, 0xdd6c, 0xcd4d, 0xbdaa, 0xad8b, 0x9de8, 0x8dc9,
    0x7c26, 0x6c07, 0x5c64, 0x4c45, 0x3ca2, 0x2c83, 0x1ce0, 0x0cc1,
    0xef1f, 0xff3e, 0xcf5d, 0xdf7c, 0xaf9b, 0xbfba, 0x8fd9, 0x9ff8,
    0x6e17, 0x7e36, 0x4e55, 0x5e74, 0x2e93, 0x3eb2, 0x0ed1, 0x1ef0
};

static void crc_update(SPIDriver *sd, const char *data, size_t data_len)
{
    unsigned int tbl_idx;
    uint16_t crc = sd->e_ccitt_crc;

    while (data_len--) {
        tbl_idx = ((crc >> 8) ^ *data) & 0xff;
        crc = (crc_table[tbl_idx] ^ (crc << 8)) & 0xffff;
        data++;
    }
    sd->e_ccitt_crc = crc;
}

// ******************************  SPIDriver  *********************************
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

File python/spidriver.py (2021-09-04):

# coding=utf-8
import sys

import serial

__version__ = '1.1.1'

PYTHON2 = (sys.version_info < (3, 0))


class SPIDriver:
    """
    SPIDriver interface.

    :param port: The USB port to connect to
    :type port: str

    After connection, the following object variables reflect the current values of the SPIDriver.
    They are updated by calling :py:meth:`getstatus`.

    :ivar product:     product code e.g. 'spidriver1' or 'spidriver2'
    :ivar serial:      serial string of SPIDriver
    :ivar uptime:      time since SPIDriver boot, in seconds
    :ivar voltage:     USB voltage, in V
    :ivar current:     current used by attached device, in mA
    :ivar temp:        temperature, in degrees C
    :ivar cs:          state of CS pin
    :ivar a:           state of A pin
    :ivar b:           state of B pin
    :ivar ccitt_crc:   CCITT-16 CRC of all transmitted and received bytes

    """

    def __init__(self, port="/dev/ttyUSB0"):
        self.ser = serial.Serial(port, 460800, timeout=1)

        self.ser.write(b'@' * 64)
        while self.ser.inWaiting():
            self.ser.read(1)

        for c in [0x55, 0x00, 0xff, 0xaa]:
            r = self.__echo(c)
            if r != c:
                print('Echo test failed - not attached?')
                print('Expected %r but received %r' % (c, r))
                raise IOError
        self.getstatus()

    if PYTHON2:
        def __ser_w(self, s):
            if isinstance(s, list):
                s = "".join([chr(c) for c in s])
            self.ser.write(s)
    else:
        def __ser_w(self, s):
            if isinstance(s, list):
                s = bytes(s)
            self.ser.write(s)

    def __echo(self, c):
        self.__ser_w([ord('e'), c])
        r = self.ser.read(1)
        if PYTHON2:
            return ord(r[0])
        else:
            return r[0]

    def detach(self):
        """ Detach all signals, leaving them all to float. """
        self.ser.write(b'x')

    def sel(self):
        """ Select the SPI device by asserting CS """
        self.ser.write(b's')

    def unsel(self):
        """ Unselect the SPI device by deasserting CS """
        self.ser.write(b'u')

    def read(self, l):
        """
        Read l bytes from the SPI device

        :param int l: number of bytes to read
        :return bytes: received bytes, length ``l``

        """
        r = []
        for i in range(0, l, 64):
            rem = min(l - i, 64)
            self.__ser_w([0x80 + rem - 1] + [0xff] * rem)
            r.append(self.ser.read(rem))
        return b''.join(r)

    def write(self, bb):
        """
        Write bb to the SPI device
        
        :param bytes bb: bytes to write to the SPI device
        """
        for i in range(0, len(bb), 64):
            sub = bb[i:i + 64]
            self.__ser_w([0xc0 + len(sub) - 1])
            self.__ser_w(sub)

    def writeread(self, bb):
        """
        Write bytes to the SPI device, return the read bytes
        
        :param bytes bb: bytes to write to the SPI device
        :return bytes: received bytes, same length as ``bb``
        """
        r = []
        ST = 64
        for i in range(0, len(bb), ST):
            sub = bb[i:i + 64]
            self.__ser_w([0x80 + len(sub) - 1])
            self.__ser_w(sub)
            r.append(self.ser.read(len(sub)))
        return b''.join(r)

    def seta(self, v):
        """ Set the A signal to 0 or 1 """
        self.__ser_w([ord('a'), v])

    def setb(self, v):
        """ Set the B signal to 0 or 1 """
        self.__ser_w([ord('b'), v])

    def setmode(self, m):
        """ Set the SPI mode to 0,1,2 or 3 """
        assert m in (0, 1, 2, 3)
        if self.product == 'spidriver1':
            if mode != 0:
                raise IOError
        elif self.product == 'spidriver2':
            self.__ser_w([ord('m'), m])
        else:
            assert 0, "Unrecognized product"

    def getstatus(self):
        """ Update all status variables """
        self.ser.write(b'?')
        r = self.ser.read(80)
        body = r[1:-1].decode()  # remove [ and ]
        fields = body.split()
        (self.product,
         self.serial,
         uptime,
         voltage,
         current,
         temp,
         a,
         b,
         cs,
         ccitt_crc) = fields[:10]
        self.uptime = int(uptime)
        self.voltage = float(voltage)
        self.current = float(current)
        self.temp = float(temp)
        self.a = int(a)
        self.b = int(b)
        self.cs = int(cs)
        self.ccitt_crc = int(ccitt_crc, 16)
        if self.product == 'spidriver2':
            self.mode = int(fields[10])
        else:
            self.mode = 0

    def __repr__(self):
        return "<%s serial=%s uptime=%d>" % (
            self.product,
            self.serial,
            self.uptime)

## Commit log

2018-04-03 Link to PCB image
2018-05-03 C/C++ bindings for Linux
    [spi.c, spidriver.c]
2018-05-03 Using cfmakeraw() avoids hang on first read on rPi
    [spidriver.c]
2018-05-05 LED string driver
2018-05-05 Slow down LED cycling
2018-05-09 Report on clock drift
    [watch.py]
2018-05-12 Thrash sample
2018-05-22 Accept device name as first arg
2018-05-22 Accept device on command line
2018-06-22 Static link libstdc++, switch to true spidriver
2018-06-22 Win32 command-line takes device name
2018-06-22 Fix missing/bad device flow
    [spi.c, spidriver.c]
2018-06-22 import PCBnew
    [spidriver1.kicad_pcb]
2018-07-06 Initial import, LCD panel sample
2018-07-11 Fix some print statements
    [gui.py]
2018-08-03 Device selection
2018-08-03 Cope with missing directory properly
    [spigui.py]
2018-08-03 UI cleanups
    Enter key does transfer
    Device picker combobox is read-only
    Use monospace for logginmg window
2018-08-26 Fix for Python 2
    [st7735s.py]
2018-08-26 Print bytes as unsigned
2018-08-26 Flash sample initial version
2018-08-30 In the win32 common code, if portname starts with 'C' insert the prefix \\.\
    [#6]
2018-09-01 First cut of the iceprog
2018-09-01 Removed extraneous material
2018-09-04 fix baud rate on osx?
    [spidriver.c]
2018-09-05 Pure Python RGB565 encoder for better portability
2019-01-13 python/samples/flash.py: Add size option
    Some flash chips do not provide the flash size in the second byte of the
    device ID, which can either cause the wrong number of bytes to be
    read/written or cause idcode() to be called infinitely. The user must
    check their chip's datasheet to know whether its device ID includes its
    size or they need to specify the size with the -s option.
    Read tested with an Atmel AT26DF321 (manufacturer ID 0x1F, device ID
    0x4700).
    [flash.py]
2019-07-23 Multi flash/FRAM test board
    [flashtest.brd, flashtest.sch]
2020-01-24 Add links to .net and rust drivers
2022-01-07 gui.py: Fixup to avoid deprecated warnings
    [gui.py]
2022-01-07 gui.py: Fix Button code to work correctly
    * Dont use deprecated function.
    [gui.py]
2022-02-25 spicl: improve command arg checking
    For 'w' and 'r', a missing argument would cause a segfault. For 'a',
    'b' and 'm', the command would just be ignored. Lets try to improve that
    a little.
    [spidriver.c]
2022-03-05 Fix warnings when building with warnings enabled
    [spidriver.c]
2022-05-06 Update st7735s.py
    Replace the `array.array('B', d565h.tostring())` with `array.array('B', d565h.tobytes())` to match deprecation in Python3.
    [st7735s.py]
